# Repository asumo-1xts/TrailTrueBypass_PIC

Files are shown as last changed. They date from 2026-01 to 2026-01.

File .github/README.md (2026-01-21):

<h1 align="center">

TrailTrueBypass_PIC


</h1>

<div align="center">

**A project for a trail-bypass with an DIP8 PIC microcontroller.**






</div>

## Features

- Normal true bypass when Trail mode off
- Selectable operating mode: Alternate or Momentary
- Set the power-on state: ON or OFF
- (Option) Selectable timing to switch: when-pressed or when-released
- Automatically bypasses if power is accidentally turned off

## Verified on

- PIC12F629
- PIC12F675

## dir: KiCad

KiCad関連のファイル一式です。

ガーバーファイルは[Release](https://github.com/asumo-1xts/TrailTrueBypass_PIC/releases)からダウンロードできます。

## dir: src

PICマイコン用のソースコード群です。

プロジェクト管理の様式はVScode用のMPLAB Extension Packに準拠しています。

コンパイル後のhexファイルは[Release](https://github.com/asumo-1xts/TrailTrueBypass_PIC/releases)からダウンロードできます。

PICマイコン間で共通のソースコードは`src`直下に、そうでないものはそのハードウェアの名前の付いたディレクトリに入っています。

`src/header.h`の冒頭で所望のPICマイコンのヘッダーファイルをincludeするだけで、そのPICマイコンが書き込み対象となります。

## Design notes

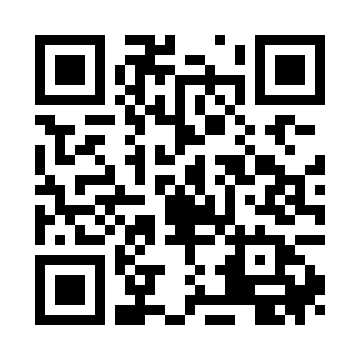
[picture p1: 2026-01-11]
KiCad/repo_QR.png

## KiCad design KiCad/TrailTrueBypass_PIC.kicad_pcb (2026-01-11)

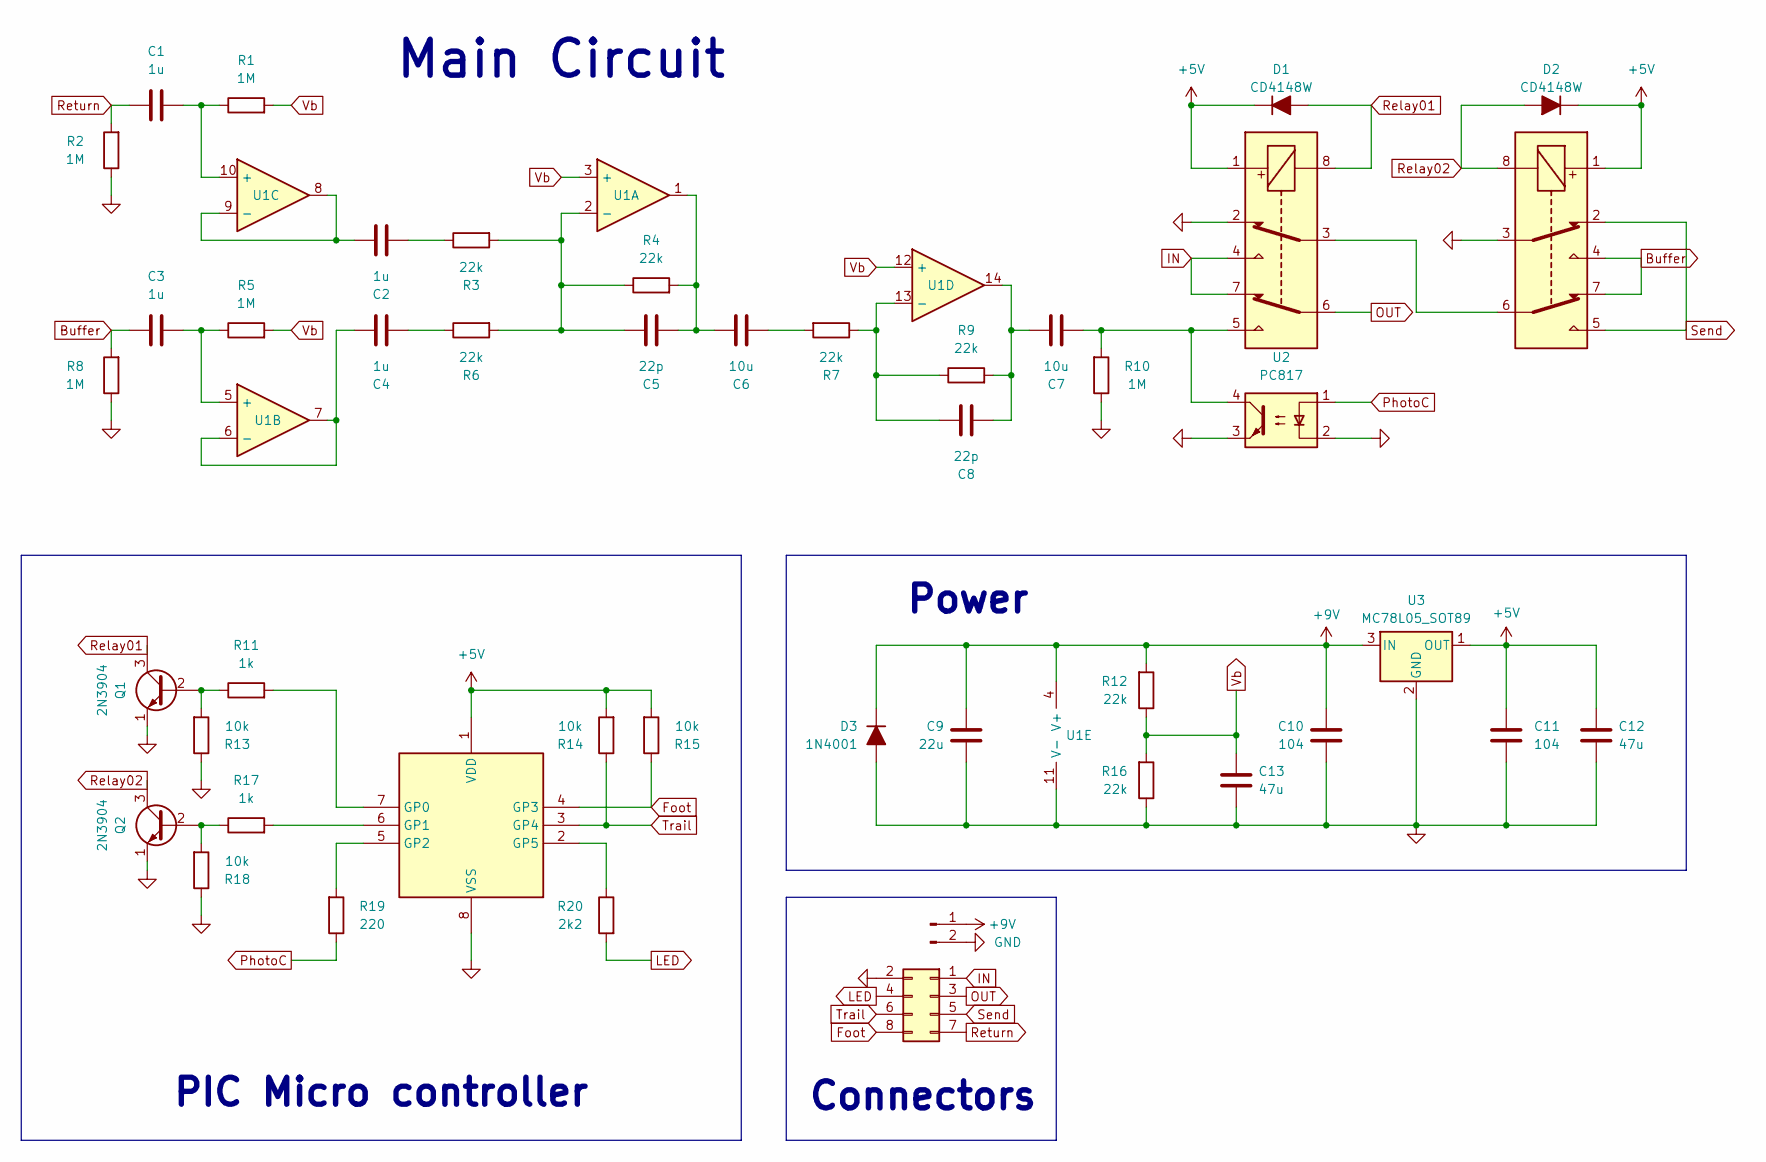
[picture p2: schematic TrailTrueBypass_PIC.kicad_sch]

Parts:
C1, C2, C3, C4: 1u; C_1206_3216Metric_Pad1.33x1.80mm_HandSolder
C5, C8: 22p; C_0402_1005Metric
C6, C7: 10u; C_1812_4532Metric_Pad1.57x3.40mm_HandSolder
C9: 22u; C_0805_2012Metric
C10, C11: 104; C_0402_1005Metric
C12: 47u; C_1206_3216Metric
C13: 47u; C_1812_4532Metric_Pad1.57x3.40mm_HandSolder
D1, D2: CD4148W; D_SOD-323
D3: 1N4001; D_SOD-123
J1: Conn_01x05_Pin; PinHeader_1x02_P2.54mm_Vertical
J2: Conn_02x04_Top_Bottom; PinHeader_2x04_P2.54mm_Vertical
K1, K2: G6S-2; Relay_DPDT_Omron_G6K-2F-Y
Q1, Q2: 2N3904; MMBT3904
R1, R2, R5, R8, R10: 1M; R_0603_1608Metric
R3, R4, R6, R7, R9: 22k; R_0603_1608Metric
R11, R17: 1k; R_0603_1608Metric
R12, R16: 22k; R_0805_2012Metric
R13, R14, R15, R18: 10k; R_0603_1608Metric
R19: 220; R_0603_1608Metric
R20: 2k2; R_0603_1608Metric
U1: Opamp_Quad; SOIC-14_3.9x8.7mm_P1.27mm
U2: PC817; DIP-4_W7.62mm
U3: MC78L05_SOT89; SOT-89-3
U4: PIC12F675-xP; DIP-8_W7.62mm_Socket

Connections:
+5V: C11.1, C12.1, D1.1 (K), D2.1 (K), K1.1, K2.1, R14.2, R15.2, U3.1 (OUT), U4.1 (VDD)
+9V: C9.1, C10.1, D3.1 (K), J1.1, R12.2, U1.4 (V+), U3.3 (IN)
Buffer: C3.1, K2.4, K2.7, R8.2
Foot: J2.8, R15.1, U4.4 (GP3)
GND: C9.2, C10.2, C11.2, C12.2, C13.2, D3.2 (A), J1.2, J2.2, K1.2, K2.3, Q1.1 (E), Q2.1 (E), R2.1, R8.1, R10.1, R13.1, R16.1, R18.1, U1.11 (V-), U2.2, U2.3, U3.2 (GND), U4.8 (VSS)
IN: J2.1, K1.4, K1.7
LED: J2.4, R20.2
unnamed: C2.2, R3.1
unnamed: C4.2, R6.1
unnamed: C5.2, C6.1, R4.2, U1.1
unnamed: C6.2, R7.2
unnamed: C7.1, K1.5, R10.2, U2.4
unnamed: C7.2, C8.2, R9.2, U1.14
unnamed: K1.3, K2.6
unnamed: Q1.2 (B), R11.1, R13.2
unnamed: Q2.2 (B), R17.1, R18.2
unnamed: C5.1, R3.2, R4.1, R6.2, U1.2 (-)
unnamed: C3.2, R5.1, U1.5 (+)
unnamed: C4.1, U1.6 (-), U1.7
unnamed: C1.2, R1.1, U1.10 (+)
unnamed: C2.1, U1.8, U1.9 (-)
unnamed: C8.1, R7.1, R9.1, U1.13 (-)
unnamed: R11.2, U4.7 (GP0)
unnamed: R17.2, U4.6 (GP1)
unnamed: R19.2, U4.5 (GP2)
unnamed: R20.1, U4.2 (GP5)
OUT: J2.3, K1.6
PhotoC: R19.1, U2.1
Relay01: D1.2 (A), K1.8, Q1.3 (C)
Relay02: D2.2 (A), K2.8, Q2.3 (C)
Return: C1.1, J2.7, R2.2
Send: J2.5, K2.2, K2.5
Trail: J2.6, R14.1, U4.3 (GP4)
Vb: C13.1, R1.2, R5.2, R12.1, R16.2, U1.3 (+), U1.12 (+)

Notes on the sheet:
Main Circuit
Connectors
Power
PIC Micro controller

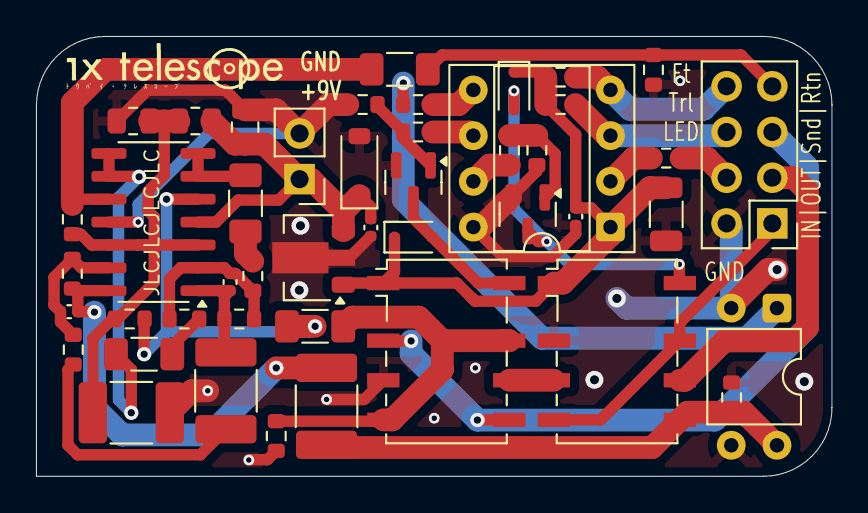
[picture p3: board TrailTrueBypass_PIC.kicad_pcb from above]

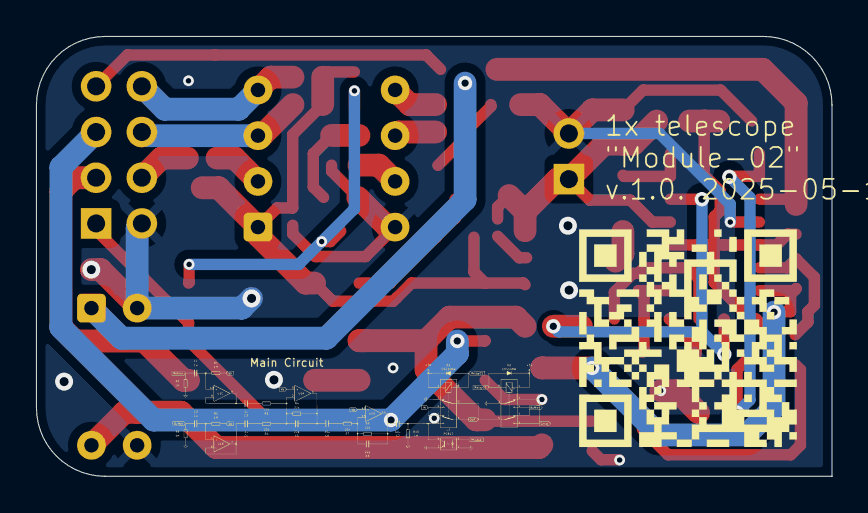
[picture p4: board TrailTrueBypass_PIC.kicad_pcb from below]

Board: 2 copper layers, 44.2 x 24.4 mm, 49 parts (2 on the bottom side), 34 nets.

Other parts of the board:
G1, G2, G3: LOGO

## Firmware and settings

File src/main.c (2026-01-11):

/**
 * @file        main.c
 * @author      aSumo
 * @version     2.0
 * @date        2025-05-12
 * @copyright   (c) 2024 aSumo
 * @brief       Program for Trail True Bypass with PIC microcontroller.
 */

#include "header.h"

/**
 * @fn      void main(void)
 * @brief   サボり上司
 */
int main(void) {
  init();
  bypass();

  return 0;
}

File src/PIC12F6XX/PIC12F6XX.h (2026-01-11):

#ifndef PIC12F6XX_H
#define PIC12F6XX_H

#include <stdbool.h>
#include <stdint.h>
#include <xc.h>

#define _XTAL_FREQ 4000000  //!< クロック周波数         4MHz

#pragma config FOSC = INTRCIO  // 内部クロック          使用
#pragma config WDTE = OFF      // Watch-Dogタイマー     不使用
#pragma config PWRTE = ON      // パワーアップタイマー  使用
#pragma config MCLRE = OFF     // リセットピン          不使用
#pragma config BOREN = ON      // Brown-Out検出         使用
#pragma config CP = ON         // プログラム保護        使用
#pragma config CPD = ON        // データ保護            使用

// ピンアウト
#define Relay01 GP0       //!< Relayピンその1
#define Relay02 GP1       //!< Relayピンその2
#define PhotoCoupler GP2  //!< Relayピンその3
#define FootSwitch GP3    //!< FootSwitchピン（Momentary）
#define ModeSwitch GP4    //!< ModeSwitchピン（Alternate）
#define LED GP5           //!< LEDピン

// EEPROMから読み込むグローバル変数
extern bool initState;  // ペダルの初期状態
extern bool momentary;  // モーメンタリ動作の是非
extern bool timing;     // オルタネイト動作時、いつ反転するか

// 関数のプロトタイプ宣言
uint8_t eepRead(uint8_t adress);
void eepWrite(uint8_t adress, uint8_t myData);
void init(void);

#endif /* PIC12F6XX_H */
